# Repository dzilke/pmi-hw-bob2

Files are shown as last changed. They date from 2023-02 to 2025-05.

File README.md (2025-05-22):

# PMI backplane BreakOut Board for BreakOut Boards (BoB²)

This pcb is designed for the course PMI (Practical course Microcontroller
and Interface electronics) as a breakout board for right morpho connector
(CN10) of [STM32 Nucleo-64 boards](https://www.st.com/en/evaluation-tools/stm32-nucleo-boards.html). It distributes several signals and bus systems like SPI, I²C, 1-wire, UART and GPIOs. Signal distribution is achieved by pin sockets and headers. The headers can be used to tap signal for anaysis with oscilloscopes or logic analyzers. It also features a 3.3V LDO voltage regulator for power supply and an on board 1-wire DS18B20+ temperature sensor. SPI Chip selects, I²C pull-up resistors and 1-wire parasitic power supply can be enabled over solder bridges.

There are interfaces for GY-291 (ADXL345 accelerometer) and GY-271 (HMC5883L magnet sensor) as well as for our [PMI-ALICE](https://github.com/emtpb/pmi-hw-alice) and [PMI-CARLOS](https://github.com/emtpb/pmi-hw-carlos) breakout boards. Vertical pin sockets are compatible with
[Digilents Pmod](https://digilent.com/reference/pmod/start) interfaces.

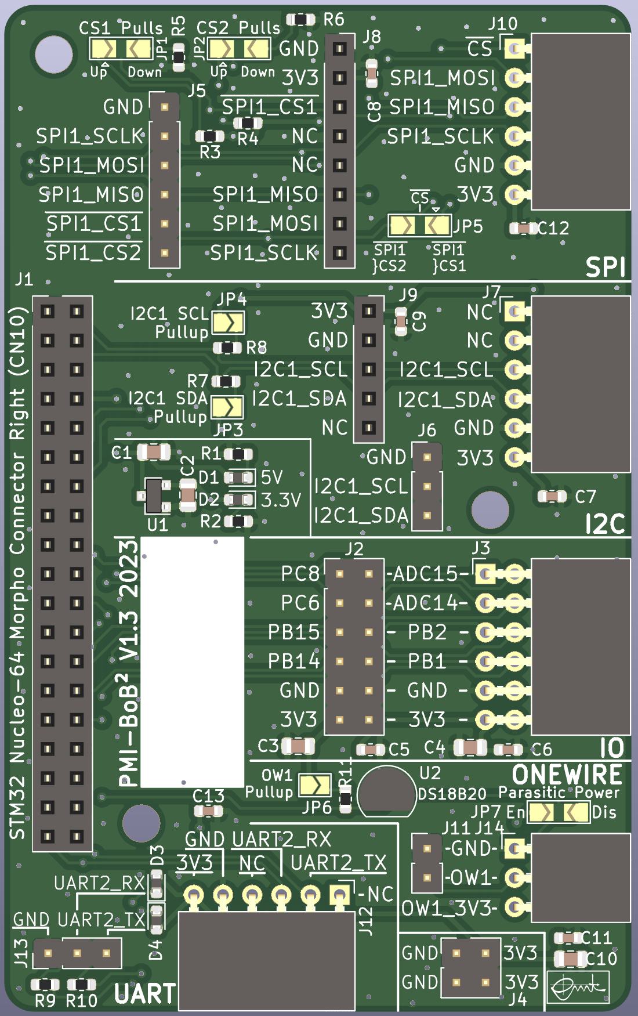
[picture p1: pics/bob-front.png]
BOB2-front


# Interactive BOM

An interactive html BOM page with pcb layout and material placement can be found [here](https://emtpb.github.io/pmi-hw-bob2/bom/ibom.html).

# Changelog

## 1.0
* First prototype

## 1.1
* First release

## 1.2
* onewire: Add parasitic power bridge
* pcb: Increase spacing between power section and morpho socket

## 1.3
* Convert project to Kicad 6
* Round pcb corners
* Update linear regulator from MCP1703T-3302E/CB to MCP1703AT-3302E/CB

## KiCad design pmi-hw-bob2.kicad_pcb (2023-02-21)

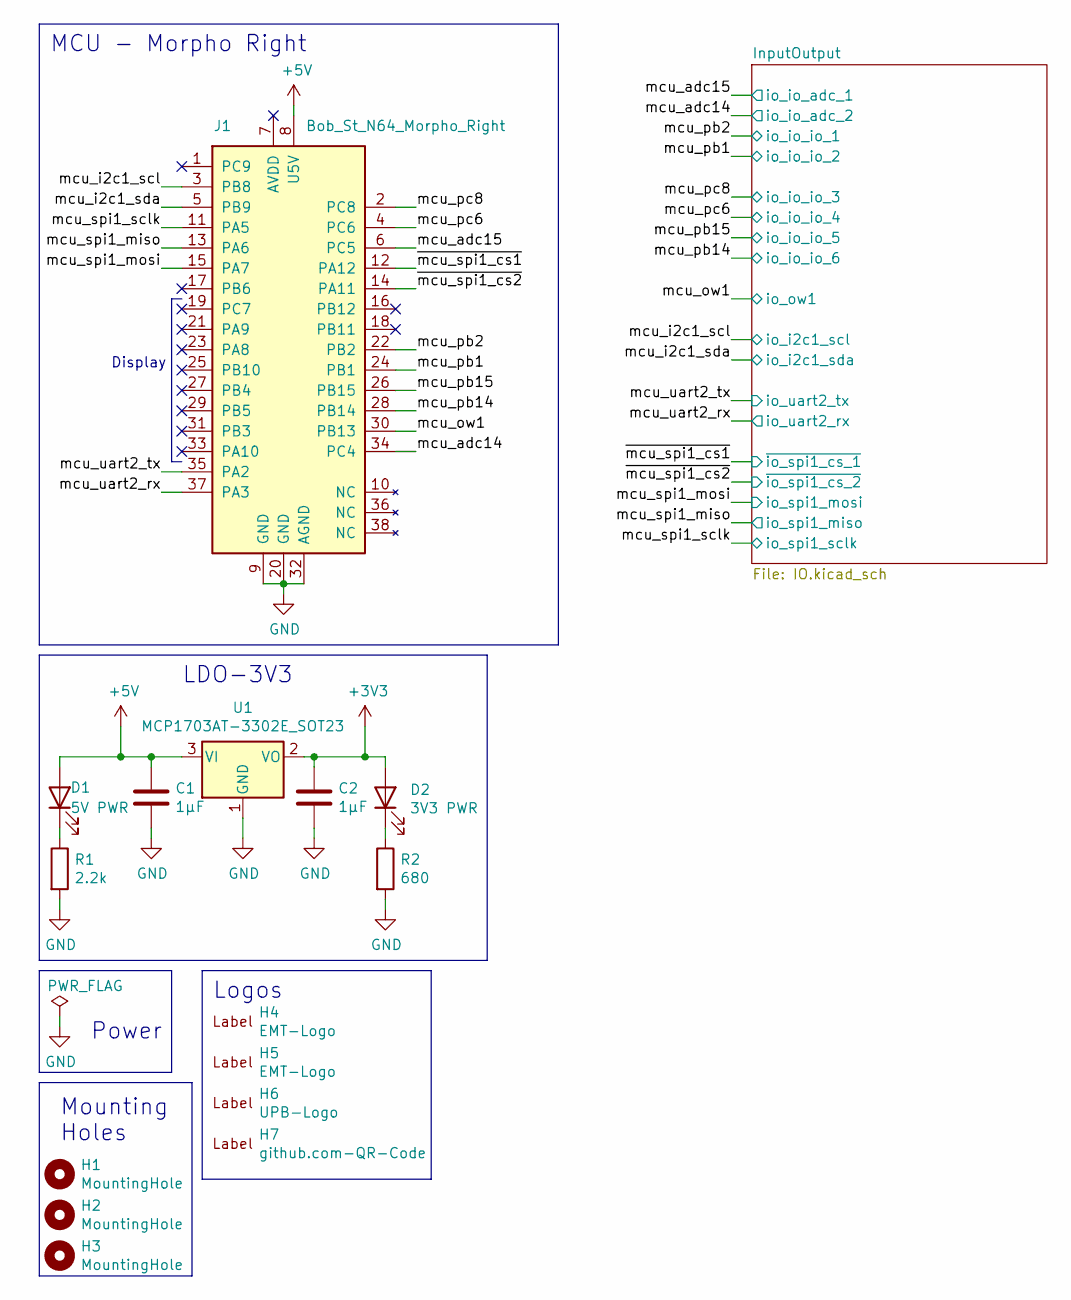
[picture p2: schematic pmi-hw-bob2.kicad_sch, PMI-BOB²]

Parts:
C1, C2: 1µF; C_0805_2012Metric
D1: 5V PWR; D_0603_1608Metric; Manufacturer Part No LB L293-M2P1-36-1; Digi-Key No 475-1383-1-ND
D2: 3V3 PWR; D_0603_1608Metric; Manufacturer Part No LB L293-M2P1-36-1; Digi-Key No 475-1383-1-ND
H1, H2, H3: MountingHole; MountingHole_3.2mm_M3
H4: EMT-Logo; EMT-Logo_5.1x2.5mm_Silkscreen
H5: EMT-Logo; EMT-Logo_11.7x5.9mm_Silkscreen
H6: UPB-Logo; UPB-Logo_En_15.9X5.6mm
H7: github.com-QR-Code; github-emtpb-pmi
J1: Bob_St_N64_Morpho_Right; ST_N64_Morpho_Right-emt
R1: 2.2k; R_0603_1608Metric
R2: 680; R_0603_1608Metric
U1: MCP1703AT-3302E_SOT23; SOT-23; Mouser Part No 579-MCP1703AT3302ECB

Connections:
+3V3: C2.1, D2.2 (A), U1.2 (VO); also elsewhere on the board
+5V: C1.1, D1.2 (A), J1.8 (U5V), U1.3 (VI)
/mcu_adc14: J1.34 (PC4); also elsewhere on the board
/mcu_adc15: J1.6 (PC5); also elsewhere on the board
/mcu_i2c1_scl: J1.3 (PB8); also elsewhere on the board
/mcu_i2c1_sda: J1.5 (PB9); also elsewhere on the board
/mcu_ow1: J1.30 (PB13); also elsewhere on the board
/mcu_pb1: J1.24 (PB1); also elsewhere on the board
/mcu_pb2: J1.22 (PB2); also elsewhere on the board
/mcu_pb14: J1.28 (PB14); also elsewhere on the board
/mcu_pb15: J1.26 (PB15); also elsewhere on the board
/mcu_pc6: J1.4 (PC6); also elsewhere on the board
/mcu_pc8: J1.2 (PC8); also elsewhere on the board
/mcu_spi1_miso: J1.13 (PA6); also elsewhere on the board
/mcu_spi1_mosi: J1.15 (PA7); also elsewhere on the board
/mcu_spi1_sclk: J1.11 (PA5); also elsewhere on the board
/mcu_uart2_rx: J1.37 (PA3); also elsewhere on the board
/mcu_uart2_tx: J1.35 (PA2); also elsewhere on the board
/~mcu_spi1_cs1: J1.12 (PA12); also elsewhere on the board
/~mcu_spi1_cs2: J1.14 (PA11); also elsewhere on the board
GND: C1.2, C2.2, J1.9 (GND), J1.20 (GND), J1.32 (AGND), R1.2, R2.2, U1.1 (GND); also elsewhere on the board
unnamed: D1.1 (K), R1.1
unnamed: D2.1 (K), R2.1

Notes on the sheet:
Mounting Holes
LDO-3V3
Logos
Display
MCU - Morpho Right
Power

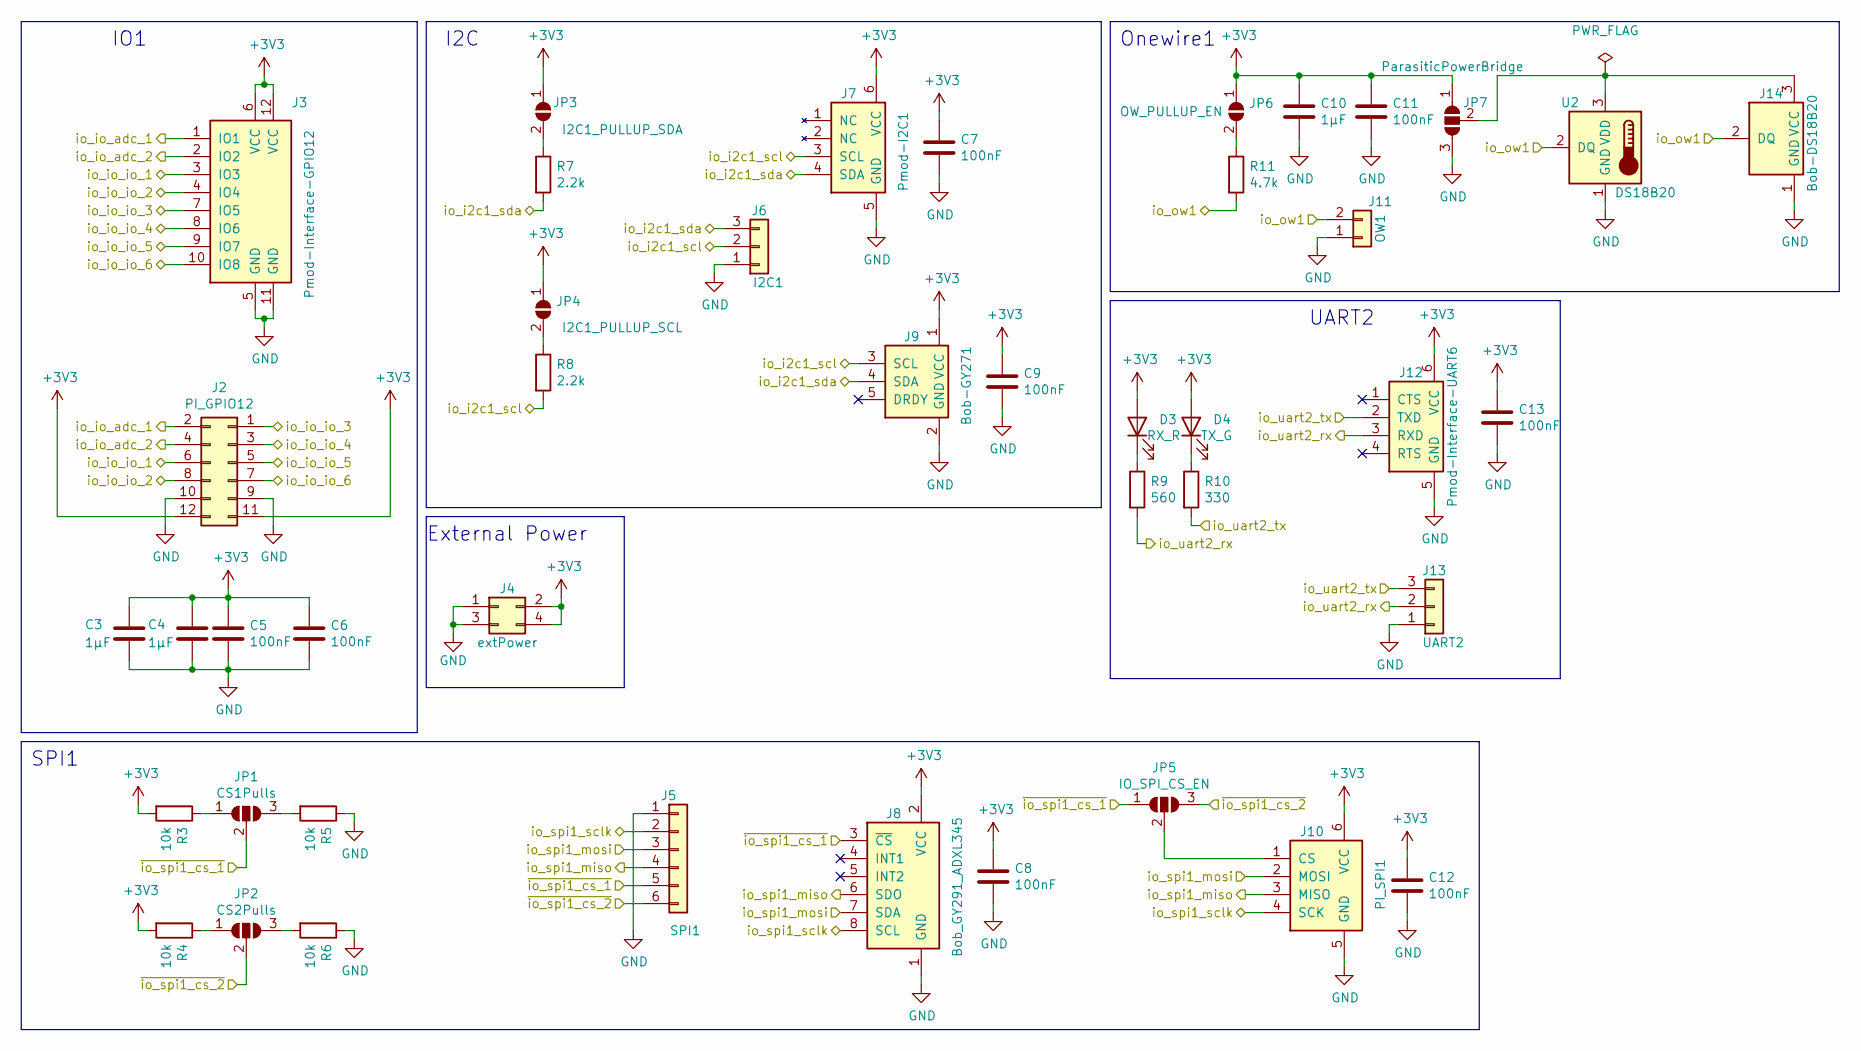
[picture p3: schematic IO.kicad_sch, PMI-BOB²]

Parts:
C3, C4, C10: 1µF; C_0805_2012Metric
C5, C6, C7, C8, C9, C11, C12, C13: 100nF; C_0603_1608Metric
D3: RX_R; D_0603_1608Metric; Manufacturer Part No LS L29K-G1H2-1-Z; Digi-Key No 475-3124-1-ND
D4: TX_G; D_0603_1608Metric; Manufacturer Part No LG L29K-F2J1-24-Z; Digi-Key No 475-3118-1-ND
J2: PI_GPIO12; PinHeader_2x06_P2.54mm_Vertical
J3: Pmod-Interface-GPIO12; Pmod_Interface_Female12
J4: extPower; PinHeader_2x02_P2.54mm_Vertical
J5: SPI1; PinHeader_1x06_P2.54mm_Vertical
J6: I2C1; PinHeader_1x03_P2.54mm_Vertical
J7: Pmod-I2C1; Pmod_Interface_Female6
J8: Bob_GY291_ADXL345; PinSocket_1x08_P2.54mm_Vertical
J9: Bob-GY271; PinSocket_1x05_P2.54mm_Vertical
J10: PI_SPI1; Pmod_Interface_Female6
J11: OW1; PinHeader_1x02_P2.54mm_Vertical
J12: Pmod-Interface-UART6; Pmod_Interface_Female6
J13: UART2; PinHeader_1x03_P2.54mm_Vertical
J14: Bob-DS18B20; Bob_DS18B20_Host
JP1: CS1Pulls; SolderJumper-3_P2.0mm_Open_TrianglePad1.0x1.5mm
JP2: CS2Pulls; SolderJumper-3_P2.0mm_Open_TrianglePad1.0x1.5mm
JP3: I2C1_PULLUP_SDA; SolderJumper-2_P1.3mm_Open_TrianglePad1.0x1.5mm
JP4: I2C1_PULLUP_SCL; SolderJumper-2_P1.3mm_Open_TrianglePad1.0x1.5mm
JP5: IO_SPI_CS_EN; SolderJumper-3_P2.0mm_Open_TrianglePad1.0x1.5mm
JP6: OW_PULLUP_EN; SolderJumper-2_P1.3mm_Open_TrianglePad1.0x1.5mm
JP7: ParasiticPowerBridge; SolderJumper-3_P2.0mm_Open_TrianglePad1.0x1.5mm_NumberLabels
R3, R4, R5, R6: 10k; R_0603_1608Metric
R7, R8: 2.2k; R_0603_1608Metric
R9: 560; R_0603_1608Metric
R10: 330; R_0603_1608Metric
R11: 4.7k; R_0603_1608Metric
U2: DS18B20; TO-92_Inline; Mouser Part No 700-DS18B20+

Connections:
+3V3: C3.1, C4.1, C5.1, C6.1, C7.1, C8.1, C9.1, C10.1, C11.1, C12.1, C13.1, D3.2 (A), D4.2 (A), J2.11, J2.12, J3.6 (VCC), J3.12 (VCC), J4.2, J4.4, J7.6 (VCC), J8.2 (VCC), J9.1 (VCC), J10.6 (VCC), J12.6 (VCC), JP3.1 (A), JP4.1 (A), JP6.1 (A), JP7.1 (A), R3.2, R4.2; also elsewhere on the board
/mcu_adc14: J2.4, J3.2 (IO2); also elsewhere on the board
/mcu_adc15: J2.2, J3.1 (IO1); also elsewhere on the board
/mcu_i2c1_scl: J6.2, J7.3 (SCL), J9.3 (SCL), R8.2; also elsewhere on the board
/mcu_i2c1_sda: J6.3, J7.4 (SDA), J9.4 (SDA), R7.2; also elsewhere on the board
/mcu_ow1: J11.2, J14.2 (DQ), R11.2, U2.2 (DQ); also elsewhere on the board
/mcu_pb1: J2.8, J3.4 (IO4); also elsewhere on the board
/mcu_pb2: J2.6, J3.3 (IO3); also elsewhere on the board
/mcu_pb14: J2.7, J3.10 (IO8); also elsewhere on the board
/mcu_pb15: J2.5, J3.9 (IO7); also elsewhere on the board
/mcu_pc6: J2.3, J3.8 (IO6); also elsewhere on the board
/mcu_pc8: J2.1, J3.7 (IO5); also elsewhere on the board
/mcu_spi1_miso: J5.4, J8.6 (SDO), J10.3 (MISO); also elsewhere on the board
/mcu_spi1_mosi: J5.3, J8.7 (SDA), J10.2 (MOSI); also elsewhere on the board
/mcu_spi1_sclk: J5.2, J8.8 (SCL), J10.4 (SCK); also elsewhere on the board
/mcu_uart2_rx: J12.3 (RXD), J13.2, R9.2; also elsewhere on the board
/mcu_uart2_tx: J12.2 (TXD), J13.3, R10.2; also elsewhere on the board
/~mcu_spi1_cs1: J5.5, J8.3 (~CS), JP1.2 (C), JP5.1 (A); also elsewhere on the board
/~mcu_spi1_cs2: J5.6, JP2.2 (C), JP5.3 (B); also elsewhere on the board
GND: C3.2, C4.2, C5.2, C6.2, C7.2, C8.2, C9.2, C10.2, C11.2, C12.2, C13.2, J2.9, J2.10, J3.5 (GND), J3.11 (GND), J4.1, J4.3, J5.1, J6.1, J7.5 (GND), J8.1 (GND), J9.2 (GND), J10.5 (GND), J11.1, J12.5 (GND), J13.1, J14.1 (GND), JP7.3 (B), R5.1, R6.1, U2.1 (GND); also elsewhere on the board
unnamed: D3.1 (K), R9.1
unnamed: D4.1 (K), R10.1
unnamed: J10.1 (CS), JP5.2 (C)
unnamed: J14.3 (VCC), JP7.2 (C), U2.3 (VDD)
unnamed: JP1.1 (A), R3.1
unnamed: JP1.3 (B), R5.2
unnamed: JP2.1 (A), R4.1
unnamed: JP2.3 (B), R6.2
unnamed: JP3.2 (B), R7.1
unnamed: JP4.2 (B), R8.1
unnamed: JP6.2 (B), R11.1

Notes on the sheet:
UART2
External Power
Onewire1
SPI1
I2C
IO1

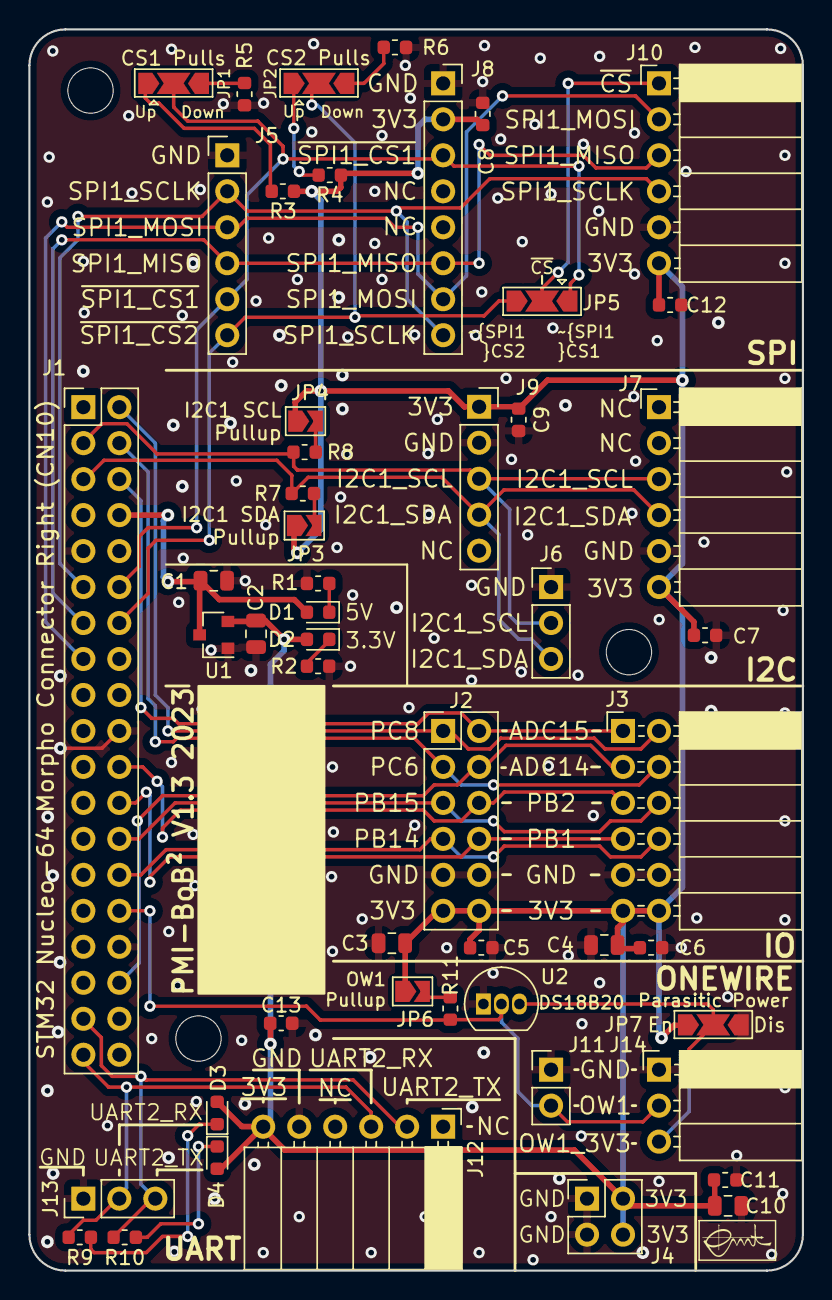
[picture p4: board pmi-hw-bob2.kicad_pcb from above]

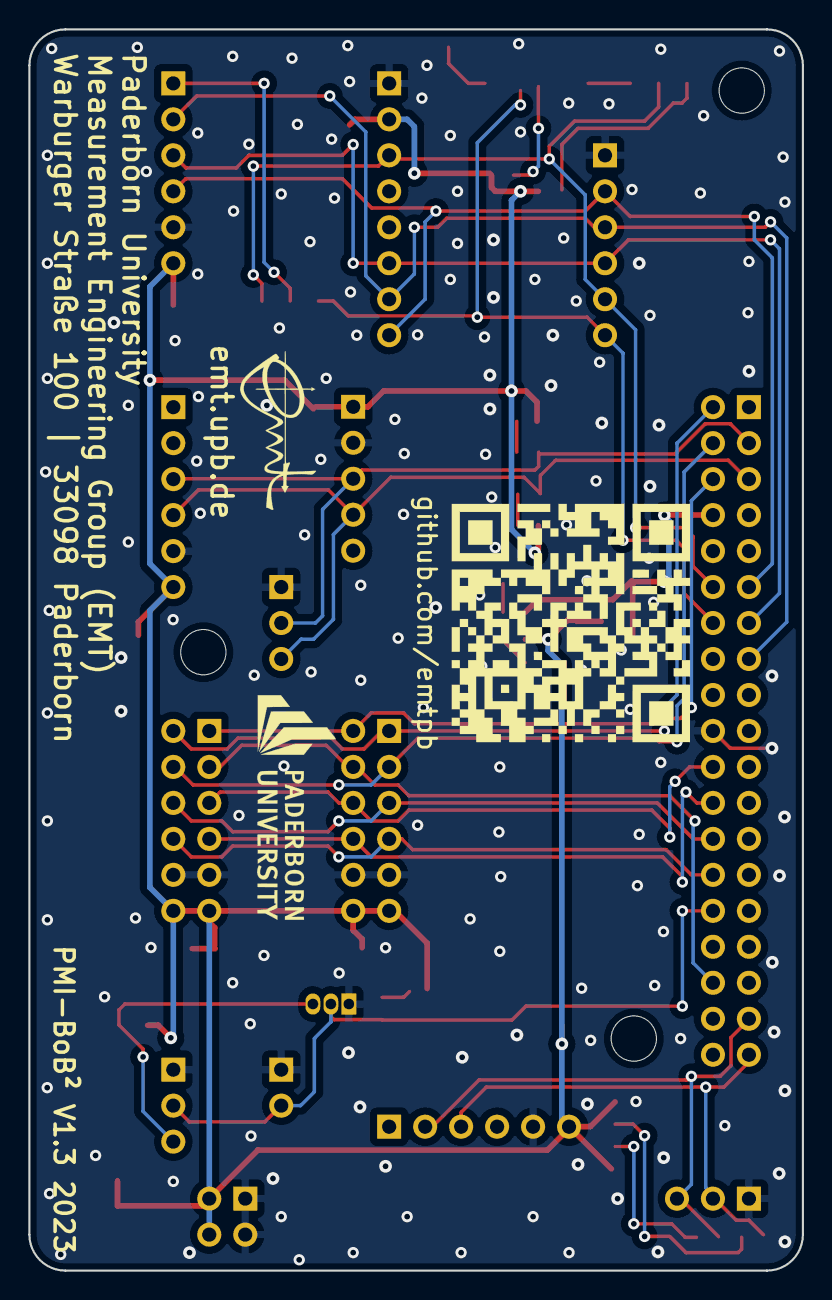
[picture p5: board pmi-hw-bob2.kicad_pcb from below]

Board: 2 copper layers, 54.6 x 87.6 mm, 58 parts (3 on the bottom side), 34 nets.

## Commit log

2021-12-23 Initial revision
    [IO.sch, pmi-hw-bob2.kicad_pcb, pmi-hw-bob2.sch]
2022-01-11 Fix empty IO.sch file
    [IO.sch]
2022-01-11 Bump to version 1.2
    [IO.sch, pmi-hw-bob2.kicad_pcb, pmi-hw-bob2.sch]
2023-02-21 Bump to version 1.3
    [IO.kicad_sch, IO.sch, pmi-hw-bob2.kicad_pcb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]
2025-05-22 Add interactive BOM link
